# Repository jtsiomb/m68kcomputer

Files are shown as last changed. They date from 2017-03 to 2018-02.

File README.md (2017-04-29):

Homebrew 68k computer project 1
===============================



About
-----
The purpose of this project is to design a minimal but useful homebrew computer,
based on the Motorola 68010 16/32-bit processor.

The current hardware design is broken into a main processor board, and an I/O
and expansion board with an AVR microcontroller playing the role of UART, timer,
and RTC all in one.

Directory structure:

  * `hw` - hardware: kicad files and pdf schematics.
  * `fw_iolite` - firmware for the I/O controller.
  * `monitor` - ROM monitor program.

Project website: http://nuclear.mutantstargoat.com/hw/m68kcomp1

License
-------
Copyright (C) 2017 John Tsiombikas <nuclear@member.fsf.org>

You are free to use, reproduce, modify, redistribute any parts of this project,
provided you make any derivative work you release, freely available under the
same terms.

More specifically the hardware parts of this project are released under the
Creative Commons Attribution Share-Alike license (see `LICENSE.hw`
for details), and the software/firmware parts are released under the GNU General
Public License v3, or later (see `LICENSE.sw` for details).

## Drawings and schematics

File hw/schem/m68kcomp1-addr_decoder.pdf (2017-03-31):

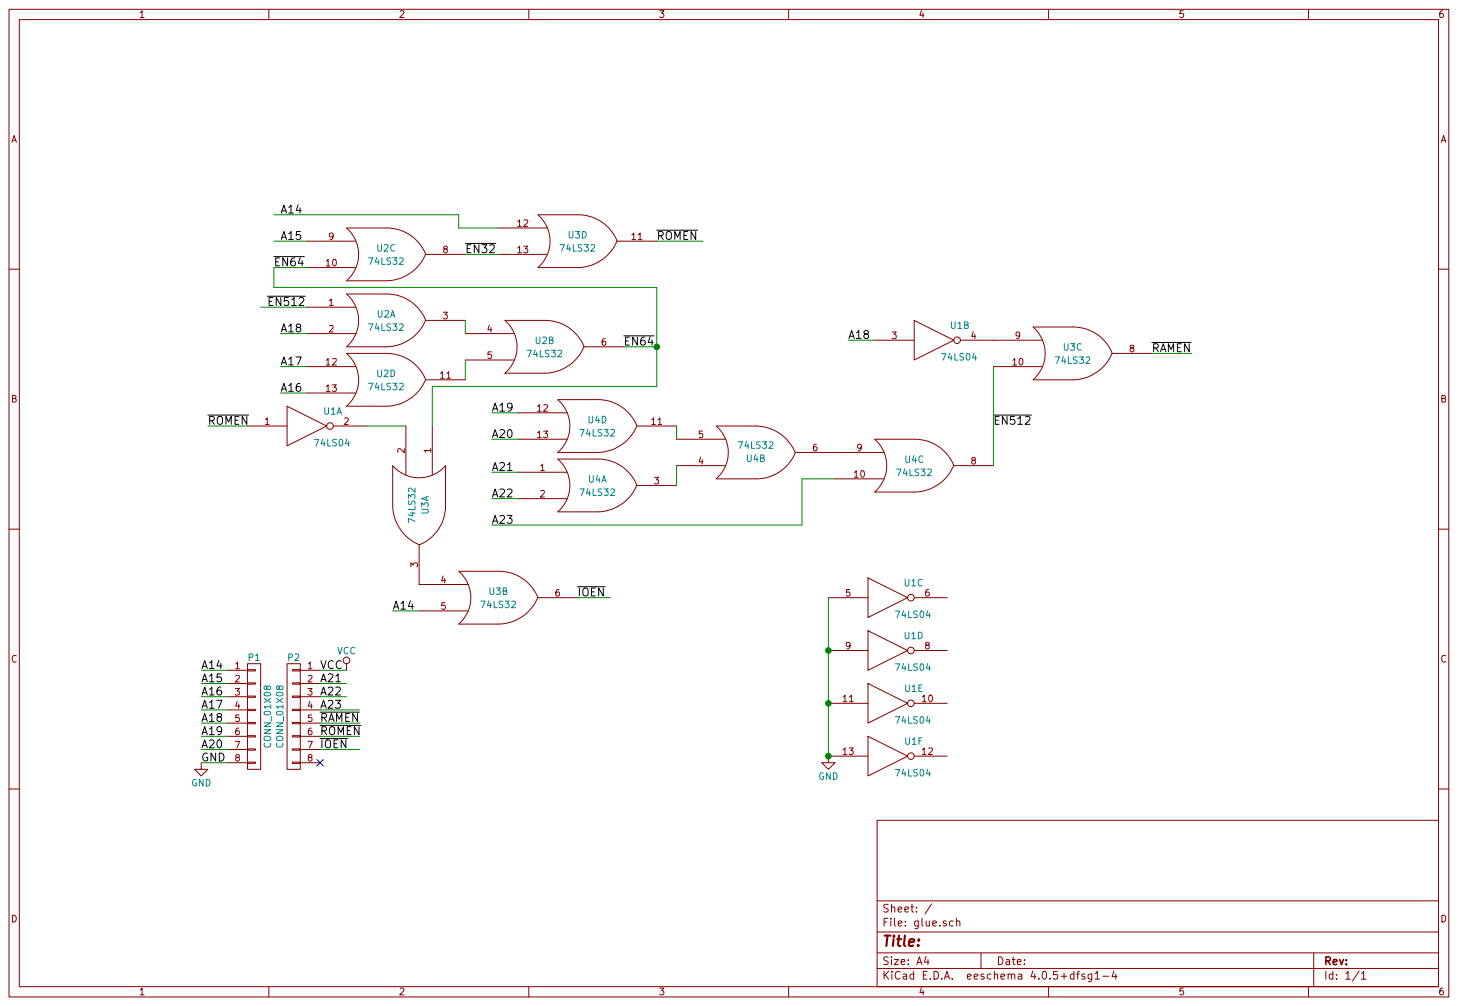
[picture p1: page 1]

File: glue.sch Sheet: /
Id: 1/1 Title:

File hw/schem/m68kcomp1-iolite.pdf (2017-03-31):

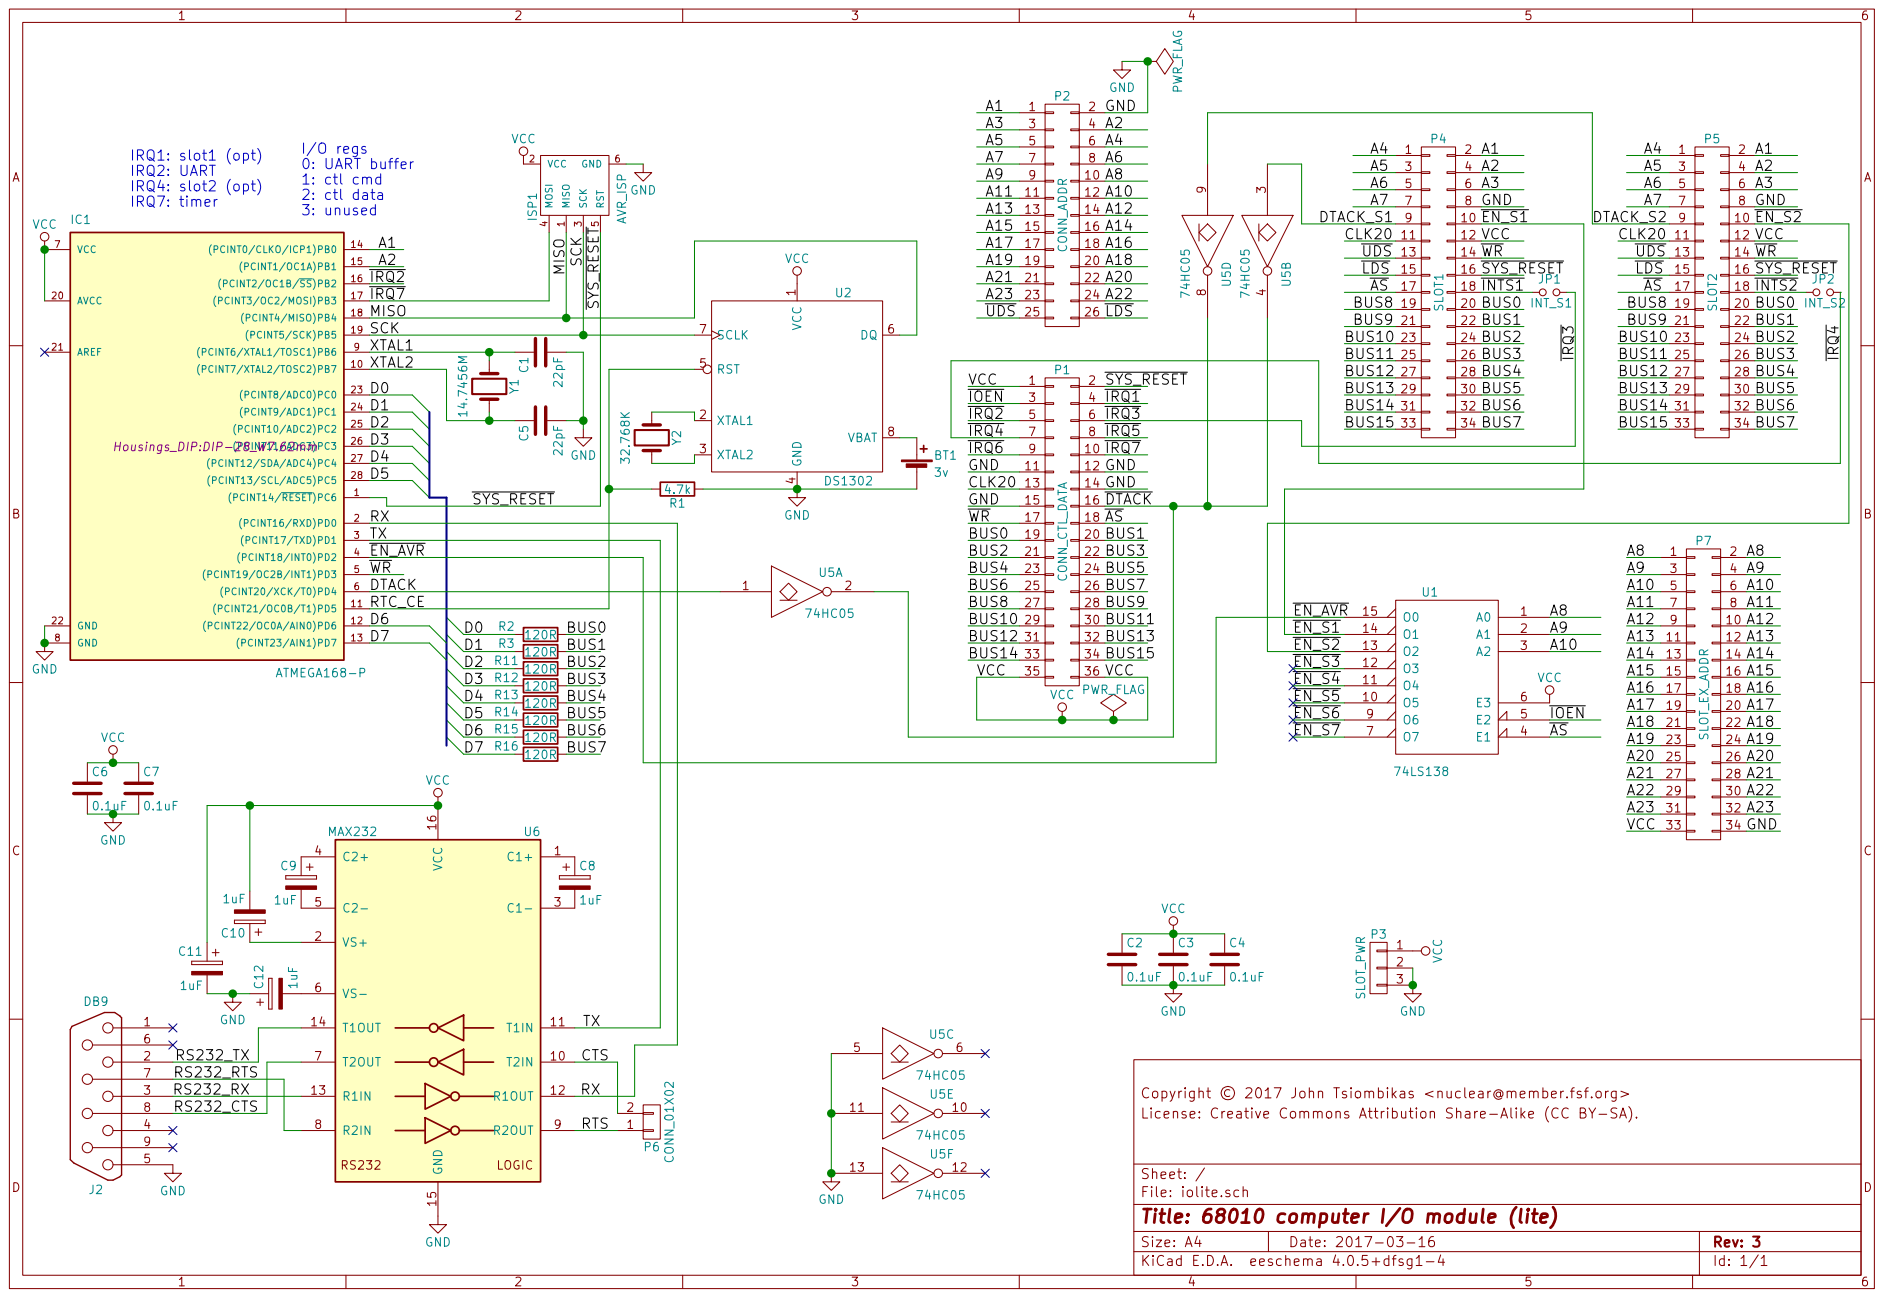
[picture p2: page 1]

I/O regs 0: UART buffer 1: ctl cmd

4 RST 5 DQ 6 SCLK 7 VBAT 8 U2 DS1302 DTACK Y2 32.768K

IOEN | 3 | | 4 | IRQ1
IRQ2 5 | | | 6 | IRQ3
IRQ4 7 | | 8 | IRQ5
IRQ6 9 | | 10 | IRQ7

3 RS232_RX

Copyright © 2017 John Tsiombikas <nuclear@member.fsf.org>
Id: 1/1 Title: 68010 computer I/O module (lite) File: iolite.sch Sheet: / License: Creative Commons Attribution Share-Alike (CC BY-SA).

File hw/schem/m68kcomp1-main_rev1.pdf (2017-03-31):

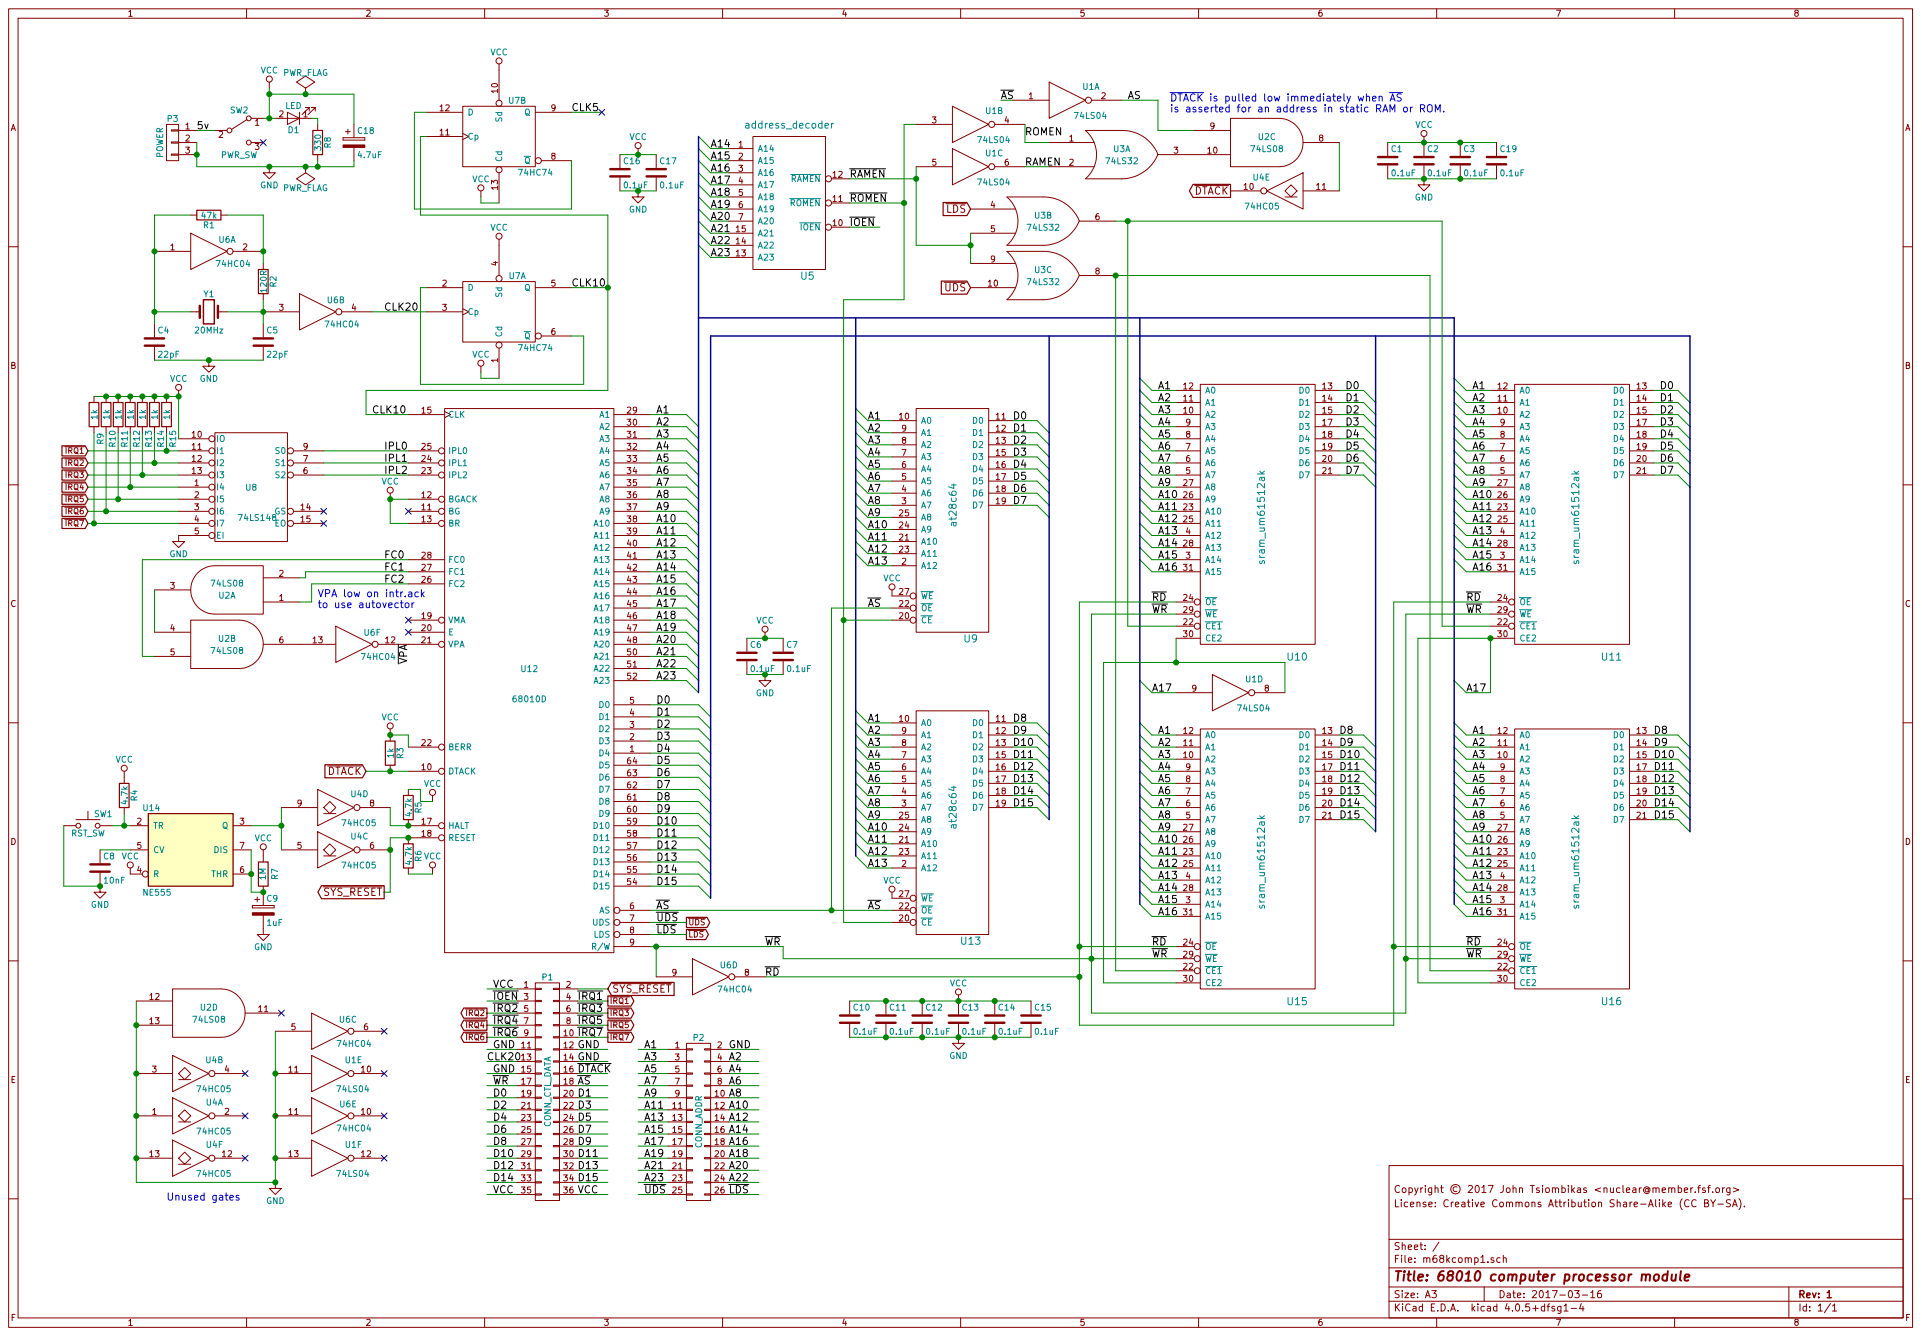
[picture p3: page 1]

DTACK is pulled low immediately when AS
is asserted for an address in static RAM or ROM.

IOEN | 3 | 4 | IRQ1
IRQ2 5 | | 6 | IRQ3
IRQ4 7 | | 8 | IRQ5

Copyright © 2017 John Tsiombikas <nuclear@member.fsf.org>
File: m68kcomp1.sch Sheet: / License: Creative Commons Attribution Share-Alike (CC BY-SA).

Id: 1/1 Title: 68010 computer processor module

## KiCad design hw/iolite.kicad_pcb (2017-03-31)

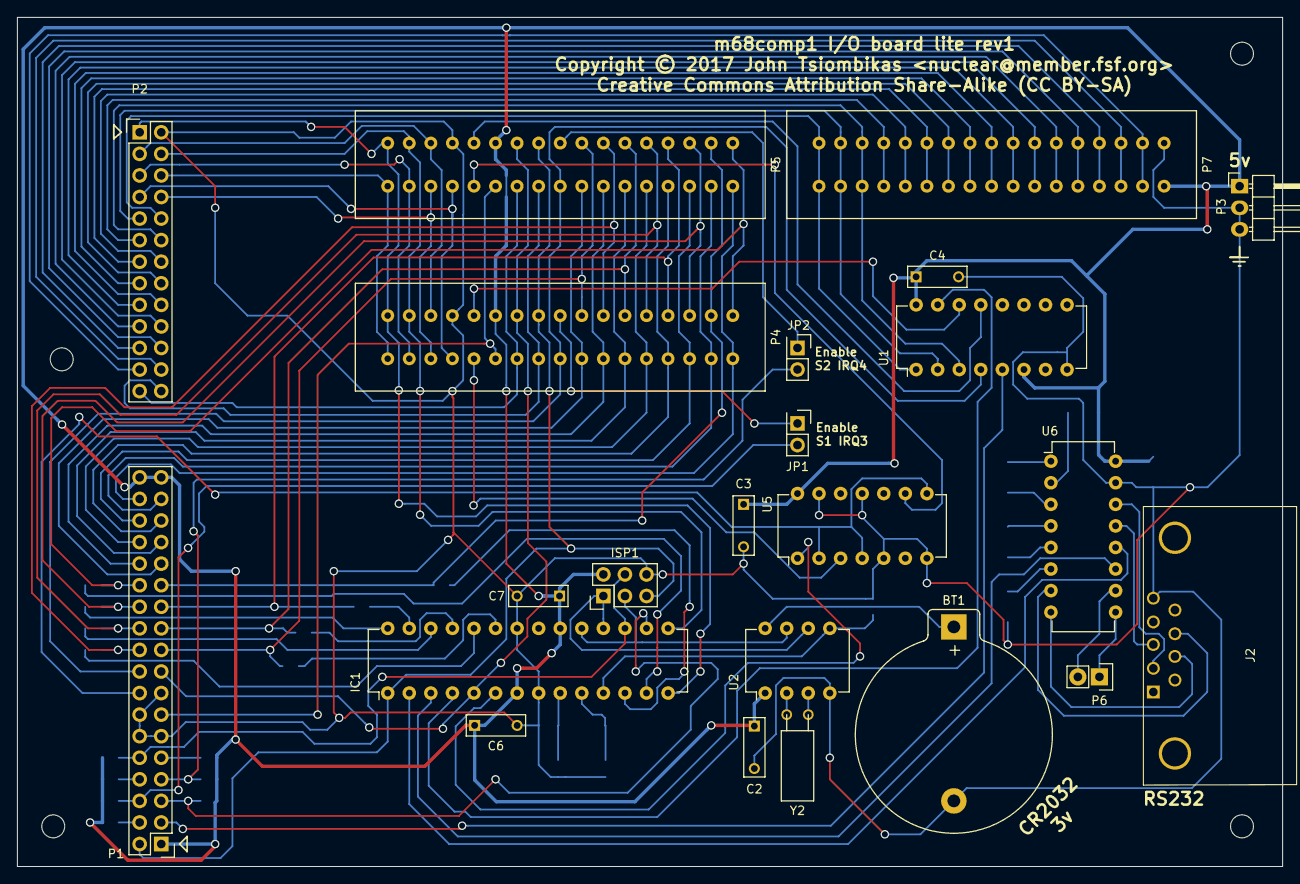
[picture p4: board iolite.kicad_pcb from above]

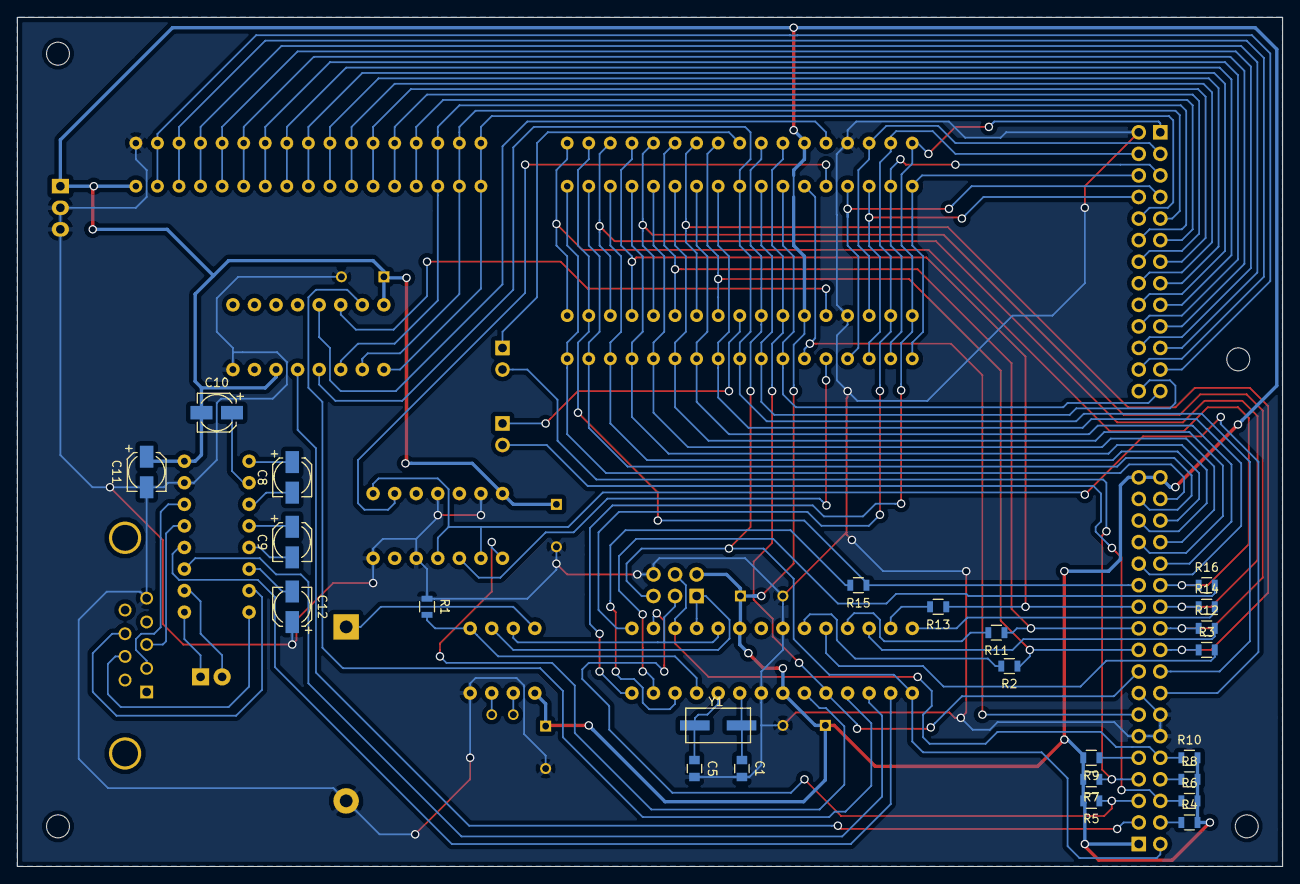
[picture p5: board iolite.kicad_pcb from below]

Board: 2 copper layers, 149.0 x 100.0 mm, 47 parts (24 on the bottom side), 94 nets.

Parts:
BT1: 3v; CR2032_CoinCell
C1, C5: 22pF; C_0805
C2, C3, C4, C6, C7: 0.1uF; C_Rect_L7_W2.5_P5
C8, C9, C10, C11, C12: 1uF; c_elec_4x5.7
IC1: ATMEGA168-P; DIP-28_W7.62mm
ISP1: AVR_ISP; Pin_Header_Straight_2x03
J2: DB9; DB9MC
JP1: INT_S1; Pin_Header_Straight_2x01
JP2: INT_S2; Pin_Header_Straight_2x01
P1: CONN_CTL_DATA; Pin_Header_Straight_2x18
P2: CONN_ADDR; Pin_Header_Straight_2x13
P3: SLOT_PWR; Pin_Header_Angled_1x03
P4: SLOT1; edgecon_2x17
P5: SLOT2; edgecon_2x17
P6: CONN_01X02; Pin_Header_Straight_1x02
P7: SLOT_EX_ADDR; edgecon_2x17
R1, R4, R5, R6, R7, R8, R9, R10: 4.7k; R_0805
R2, R3, R11, R12, R13, R14, R15, R16: 120R; R_0805
U1: 74LS138; DIP-16_W7.62mm
U2: DS1302; DIP-8_W7.62mm
U5: 74HC05; DIP-14_W7.62mm
U6: MAX232; DIP-16_W7.62mm
Y1: 14.7456M; crystal_smd_7.6x4.1
Y2: 32.768K; Crystal_Watch

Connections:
/A1: IC1.14, P2.1, P4.2, P5.2
/A2: IC1.15, P2.4, P4.4, P5.4
/A3: P2.3, P4.6, P5.6
/A4: P2.6, P4.1, P5.1
/A5: P2.5, P4.3, P5.3
/A6: P2.8, P4.5, P5.5
/A7: P2.7, P4.7, P5.7
/A8: P2.10, P7.1, P7.2, U1.1
/A9: P2.9, P7.3, P7.4, U1.2
/A10: P2.12, P7.5, P7.6, U1.3
/A11: P2.11, P7.7, P7.8
/A12: P2.14, P7.9, P7.10
/A13: P2.13, P7.11, P7.12
/A14: P2.16, P7.13, P7.14
/A15: P2.15, P7.15, P7.16
/A16: P2.18, P7.17, P7.18
/A17: P2.17, P7.19, P7.20
/A18: P2.20, P7.21, P7.22
/A19: P2.19, P7.23, P7.24
/A20: P2.22, P7.25, P7.26
/A21: P2.21, P7.27, P7.28
/A22: P2.24, P7.29, P7.30
/A23: P2.23, P7.31, P7.32
/BUS0: P1.19, P4.20, P5.20, R2.1
/BUS1: P1.20, P4.22, P5.22, R3.1
/BUS2: P1.21, P4.24, P5.24, R11.1
/BUS3: P1.22, P4.26, P5.26, R12.1
/BUS4: P1.23, P4.28, P5.28, R13.1
/BUS5: P1.24, P4.30, P5.30, R14.1
/BUS6: P1.25, P4.32, P5.32, R15.1
/BUS7: P1.26, P4.34, P5.34, R16.1
/BUS8: P1.27, P4.19, P5.19
/BUS9: P1.28, P4.21, P5.21
/BUS10: P1.29, P4.23, P5.23
/BUS11: P1.30, P4.25, P5.25
/BUS12: P1.31, P4.27, P5.27
/BUS13: P1.32, P4.29, P5.29
/BUS14: P1.33, P4.31, P5.31
/BUS15: P1.34, P4.33, P5.33
/CLK20: P1.13, P4.11, P5.11
/CTS: P6.2, U6.10
/D0: IC1.23, R2.2
/D1: IC1.24, R3.2
/D2: IC1.25, R11.2
/D3: IC1.26, R12.2
/D4: IC1.27, R13.2
/D5: IC1.28, R14.2
/D6: IC1.12, R15.2
/D7: IC1.13, R16.2
/DTACK: IC1.6, U5.1
/DTACK_S1: P4.9, U5.3
/DTACK_S2: P5.9, U5.9
/MISO: IC1.18, ISP1.1, U2.6
/RS232_CTS: J2.8, U6.7
/RS232_RTS: J2.7, U6.8
/RS232_RX: J2.3, U6.13
/RS232_TX: J2.2, U6.14
/RTC_CE: IC1.11, R1.2, U2.5
/RTS: P6.1, U6.9
/RX: IC1.2, U6.12
/SCK: IC1.19, ISP1.3, U2.7
/TX: IC1.3, U6.11
/XTAL1: C1.1, IC1.9, Y1.1
/XTAL2: C5.1, IC1.10, Y1.2
/~AS: P1.18, P4.17, P5.17, U1.4
/~DTACK: P1.16, U5.2, U5.4, U5.8
/~EN_AVR: IC1.4, U1.15
/~EN_S1: P4.10, U1.14
/~EN_S2: P5.10, U1.13
/~INTS1: JP1.1, P4.18
/~INTS2: JP2.1, P5.18
/~IOEN: P1.3, U1.5
/~IRQ1: P1.4, R4.1
/~IRQ2: IC1.16, P1.5, R5.1
/~IRQ3: JP1.2, P1.6, R6.1
/~IRQ4: JP2.2, P1.7, R7.1
/~IRQ5: P1.8, R8.1
/~IRQ6: P1.9, R9.1
/~IRQ7: IC1.17, ISP1.4, P1.10, R10.1
/~LDS: P2.26, P4.15, P5.15
/~SYS_RESET: IC1.1, ISP1.5, P1.2, P4.16, P5.16
/~UDS: P2.25, P4.13, P5.13
/~WR: IC1.5, P1.17, P4.14, P5.14
GND: BT1.2, C1.2, C2.2, C3.2, C4.2, C5.2, C6.2, C7.2, C11.2, C12.1, IC1.8, IC1.22, ISP1.6, J2.5, P1.11, P1.12, P1.14, P1.15, P2.2, P3.2, P3.3, P4.8, P5.8, P7.34, R1.1, U1.8, U2.4, U5.5, U5.7, U5.11, U5.13, U6.15
unnamed: BT1.1, U2.8
unnamed: C8.1, U6.1
unnamed: C8.2, U6.3
unnamed: C9.1, U6.4
unnamed: C9.2, U6.5
unnamed: C10.1, U6.2
unnamed: C12.2, U6.6
unnamed: U2.2, Y2.1
unnamed: U2.3, Y2.2
VCC: C2.1, C3.1, C4.1, C6.1, C7.1, C10.2, C11.1, IC1.7, IC1.20, ISP1.2, P1.1, P1.35, P1.36, P3.1, P4.12, P5.12, P7.33, R4.2, R5.2, R6.2, R7.2, R8.2, R9.2, R10.2, U1.6, U1.16, U2.1, U5.14, U6.16

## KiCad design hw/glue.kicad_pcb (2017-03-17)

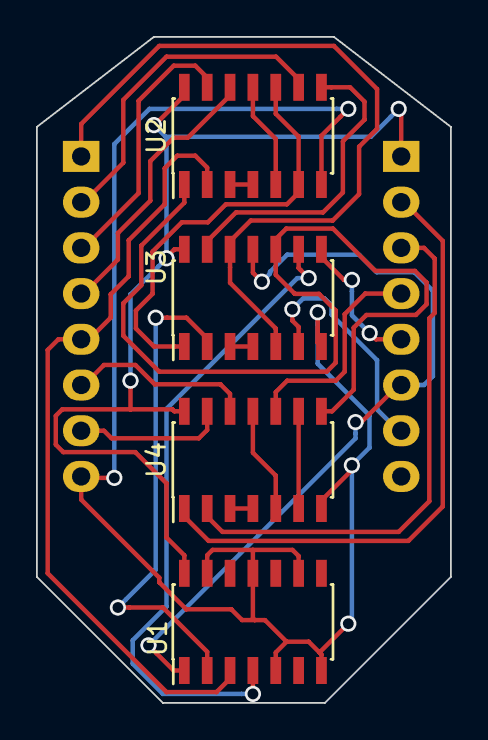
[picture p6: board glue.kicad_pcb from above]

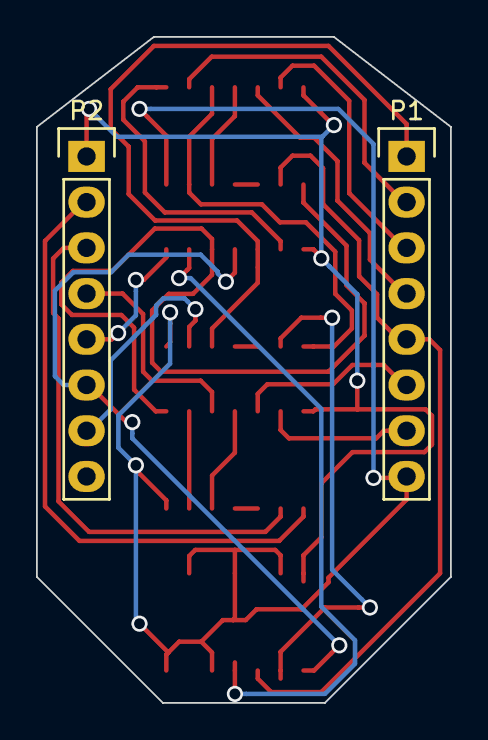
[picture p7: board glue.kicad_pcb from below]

Board: 2 copper layers, 23.0 x 37.0 mm, 6 parts (2 on the bottom side), 26 nets.

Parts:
P1, P2: CONN_01X08; Pin_Header_Straight_1x08
U1: 74LS04; SOIC-14_3.9x8.7mm_Pitch1.27mm
U2, U3, U4: 74LS32; SOIC-14_3.9x8.7mm_Pitch1.27mm

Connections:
/A14: P1.1, U3.5, U3.12
/A15: P1.2, U2.9
/A16: P1.3, U2.13
/A17: P1.4, U2.12
/A18: P1.5, U1.3, U2.2
/A19: P1.6, U4.12
/A20: P1.7, U4.13
/A21: P2.2, U4.1
/A22: P2.3, U4.2
/A23: P2.4, U4.10
/~EN32: U2.8, U3.13
/~EN64: U2.6, U2.10, U3.1
/~EN512: U2.1, U3.10, U4.8
/~IOEN: P2.7, U3.6
/~RAMEN: P2.5, U3.8
/~ROMEN: P2.6, U1.1, U3.11
GND: P1.8, U1.5, U1.7, U1.9, U1.11, U1.13, U2.7, U3.7, U4.7
unnamed: U1.2, U3.2
unnamed: U1.4, U3.9
unnamed: U2.3, U2.4
unnamed: U2.5, U2.11
unnamed: U3.3, U3.4
unnamed: U4.3, U4.4
unnamed: U4.6, U4.9
unnamed: U4.5, U4.11
VCC: P2.1, U1.14, U2.14, U3.14, U4.14

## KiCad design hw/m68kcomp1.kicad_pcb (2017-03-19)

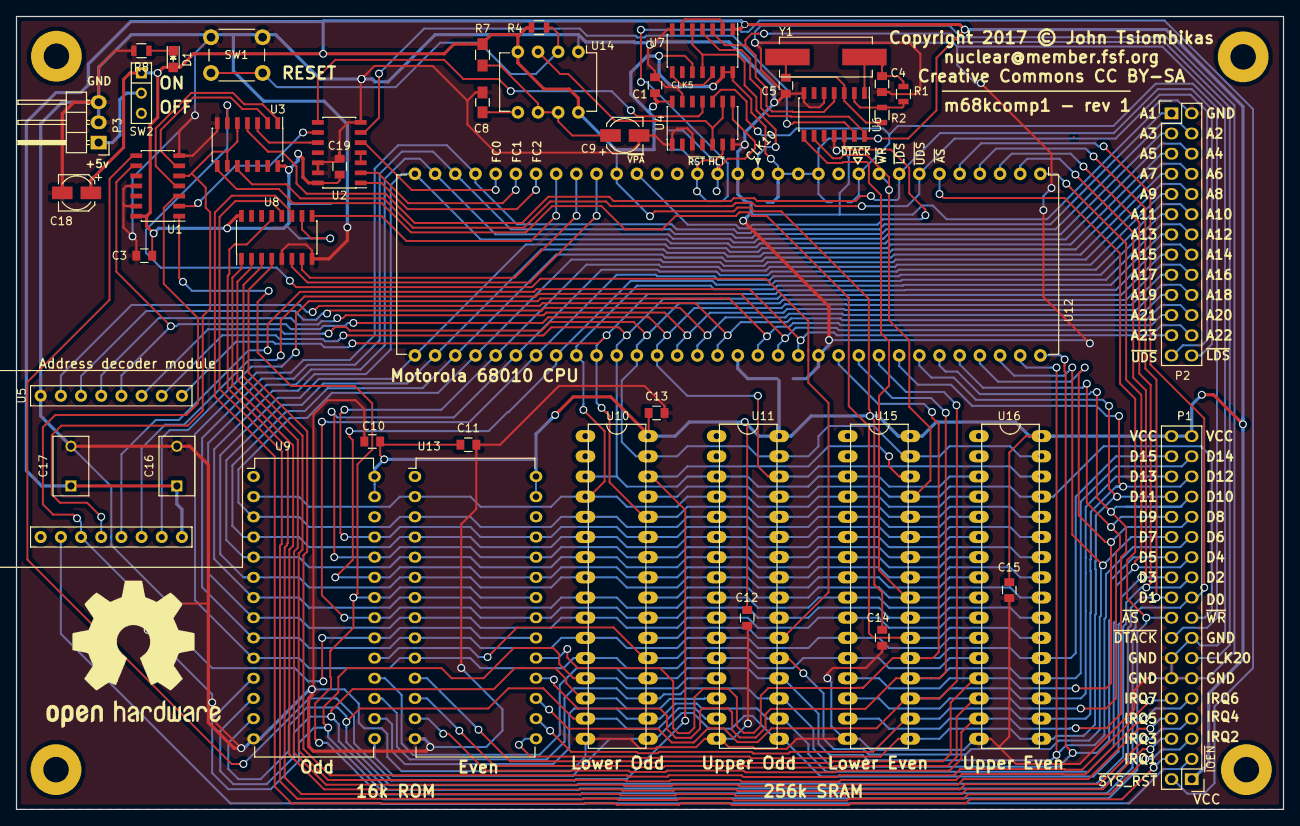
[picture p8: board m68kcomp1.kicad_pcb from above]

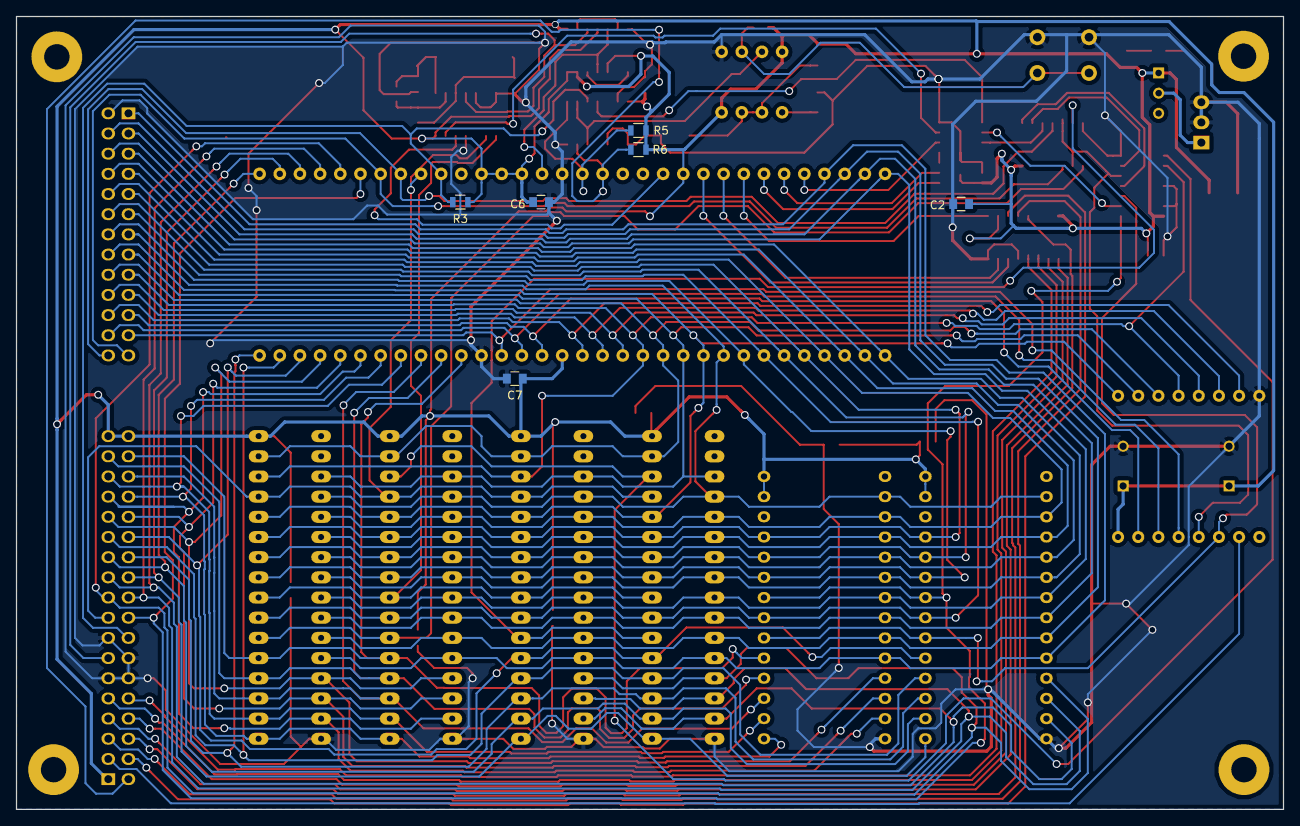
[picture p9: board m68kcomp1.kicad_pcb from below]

Board: 2 copper layers, 159.5 x 99.8 mm, 50 parts (6 on the bottom side), 89 nets.

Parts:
C1, C2, C3, C6, C7, C10, C11, C12, C13, C14, C15, C19: 0.1uF; C_0805
C4, C5: 22pF; C_0805
C8: 10nF; C_0805_HandSoldering
C9: 1uF; c_elec_4x5.7
C16, C17: 0.1uF; C_Disc_D7.5_P5
C18: 4.7uF; c_elec_4x5.7
D1: LED; LED_0805
P1: CONN_CTL_DATA; Pin_Header_Straight_2x18
P2: CONN_ADDR; Pin_Header_Straight_2x13_oval
P3: POWER; Pin_Header_Angled_1x03
R1: 47k; R_0805
R2: 120R; R_0805
R3, R4, R5, R6: 4.7k; R_0805
R7: 1M; R_0805_HandSoldering
R8: 330; R_0805
SW1: RST_SW; SW_PUSH_6mm
SW2: PWR_SW; SW_Micro_SPST
U1: 74LS04; SOIC-14_3.9x8.7mm_Pitch1.27mm
U2: 74LS08; SOIC-14_3.9x8.7mm_Pitch1.27mm
U3: 74LS32; SOIC-14_3.9x8.7mm_Pitch1.27mm
U4: 74HC05; SOIC-14_3.9x8.7mm_Pitch1.27mm
U5: address_decoder; addr_dec_module
U6: 74HC04; SOIC-14_3.9x8.7mm_Pitch1.27mm
U7: 74HC74; SOIC-14_3.9x8.7mm_Pitch1.27mm
U8: 74LS148; SOIC-16_3.9x9.9mm_Pitch1.27mm
U9, U13: at28c64; DIP-28_W15.24mm_oval
U10, U11, U15, U16: sram_um61512ak; DIP-32L
U12: 68010D; DIP-64_W22.86mm
U14: NE555; DIP-8_W7.62mm
Y1: 20MHz; Crystal_HC49-SD_SMD

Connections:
/5v: P3.1, SW2.2
/A1: P2.1, U9.10, U10.12, U11.12, U12.29, U13.10, U15.12, U16.12
/A2: P2.4, U9.9, U10.11, U11.11, U12.30, U13.9, U15.11, U16.11
/A3: P2.3, U9.8, U10.10, U11.10, U12.31, U13.8, U15.10, U16.10
/A4: P2.6, U9.7, U10.9, U11.9, U12.32, U13.7, U15.9, U16.9
/A5: P2.5, U9.6, U10.8, U11.8, U12.33, U13.6, U15.8, U16.8
/A6: P2.8, U9.5, U10.7, U11.7, U12.34, U13.5, U15.7, U16.7
/A7: P2.7, U9.4, U10.6, U11.6, U12.35, U13.4, U15.6, U16.6
/A8: P2.10, U9.3, U10.5, U11.5, U12.36, U13.3, U15.5, U16.5
/A9: P2.9, U9.25, U10.27, U11.27, U12.37, U13.25, U15.27, U16.27
/A10: P2.12, U9.24, U10.26, U11.26, U12.38, U13.24, U15.26, U16.26
/A11: P2.11, U9.21, U10.23, U11.23, U12.39, U13.21, U15.23, U16.23
/A12: P2.14, U9.23, U10.25, U11.25, U12.40, U13.23, U15.25, U16.25
/A13: P2.13, U9.2, U10.4, U11.4, U12.41, U13.2, U15.4, U16.4
/A14: P2.16, U5.1, U10.28, U11.28, U12.42, U15.28, U16.28
/A15: P2.15, U5.2, U10.3, U11.3, U12.43, U15.3, U16.3
/A16: P2.18, U5.3, U10.31, U11.31, U12.44, U15.31, U16.31
/A17: P2.17, U1.9, U5.4, U11.30, U12.45, U16.30
/A18: P2.20, U5.5, U12.46
/A19: P2.19, U5.6, U12.47
/A20: P2.22, U5.7, U12.48
/A21: P2.21, U5.15, U12.50
/A22: P2.24, U5.14, U12.51
/A23: P2.23, U5.13, U12.52
/AS: U1.2, U2.9
/CLK10: U7.5, U7.11, U12.15
/CLK20: P1.13, U6.4, U7.3
/D0: P1.19, U9.11, U10.13, U11.13, U12.5
/D1: P1.20, U9.12, U10.14, U11.14, U12.4
/D2: P1.21, U9.13, U10.15, U11.15, U12.3
/D3: P1.22, U9.15, U10.17, U11.17, U12.2
/D4: P1.23, U9.16, U10.18, U11.18, U12.1
/D5: P1.24, U9.17, U10.19, U11.19, U12.64
/D6: P1.25, U9.18, U10.20, U11.20, U12.63
/D7: P1.26, U9.19, U10.21, U11.21, U12.62
/D8: P1.27, U12.61, U13.11, U15.13, U16.13
/D9: P1.28, U12.60, U13.12, U15.14, U16.14
/D10: P1.29, U12.59, U13.13, U15.15, U16.15
/D11: P1.30, U12.58, U13.15, U15.17, U16.17
/D12: P1.31, U12.57, U13.16, U15.18, U16.18
/D13: P1.32, U12.56, U13.17, U15.19, U16.19
/D14: P1.33, U12.55, U13.18, U15.20, U16.20
/D15: P1.34, U12.54, U13.19, U15.21, U16.21
/FC0: U2.5, U12.28
/FC1: U2.2, U12.27
/FC2: U2.1, U12.26
/IPL0: U8.9, U12.25
/IPL1: U8.7, U12.24
/IPL2: U8.6, U12.23
/RAMEN: U1.6, U3.2
/ROMEN: U1.4, U3.1
/~AS: P1.18, U1.1, U9.22, U12.6, U13.22
/~IOEN: P1.3, U5.10
/~RAMEN: U1.5, U3.5, U3.9, U5.12
/~RD: U6.8, U10.24, U11.24, U15.24, U16.24
/~ROMEN: U1.3, U5.11, U9.20, U13.20
/~VPA: U6.12, U12.21
/~WR: P1.17, U6.9, U10.29, U11.29, U12.9, U15.29, U16.29
GND: C1.2, C2.2, C3.2, C4.2, C5.2, C6.2, C7.2, C8.2, C9.2, C10.2, C11.2, C12.2, C13.2, C14.2, C15.2, C16.2, C17.2, C18.2, C19.2, P1.11, P1.12, P1.14, P1.15, P2.2, P3.2, P3.3, R8.2, SW1.1, U1.7, U1.11, U1.13, U2.7, U2.12, U2.13, U3.7, U4.1, U4.3, U4.7, U4.13, U5.8, U6.5, U6.7, U6.11, U7.7, U8.5, U8.8, U9.14, U10.16, U11.16, U12.16, U12.53, U13.14, U14.1, U15.16, U16.16
unnamed: C4.1, R1.2, U6.1, Y1.1
unnamed: C5.1, R2.2, U6.3, Y1.2
unnamed: C8.1, U14.5
unnamed: C9.1, R7.1, U14.6, U14.7
unnamed: D1.1, R8.1
unnamed: R1.1, R2.1, U6.2
unnamed: R4.2, SW1.2, U14.2
unnamed: R5.2, U4.8, U12.17
unnamed: U1.8, U10.30, U15.30
unnamed: U2.3, U2.4
unnamed: U2.6, U6.13
unnamed: U2.8, U4.11
unnamed: U2.10, U3.3
unnamed: U7.2, U7.6
unnamed: U7.8, U7.12
unnamed: U3.6, U10.22, U11.22
unnamed: U4.5, U4.9, U14.3
unnamed: U3.8, U15.22, U16.22
VCC: C1.1, C2.1, C3.1, C6.1, C7.1, C10.1, C11.1, C12.1, C13.1, C14.1, C15.1, C16.1, C17.1, C18.1, C19.1, D1.2, P1.1, P1.35, P1.36, R3.1, R4.1, R5.1, R6.2, R7.2, SW2.1, U1.14, U2.14, U3.14, U4.14, U5.16, U6.14, U7.1, U7.4, U7.10, U7.13, U7.14, U8.10, U8.16, U9.27, U9.28, U10.32, U11.32, U12.12, U12.13, U12.14, U12.22, U12.49, U13.27, U13.28, U14.4, U14.8, U15.32, U16.32
~DTACK: P1.16, R3.2, U4.10, U12.10
~IRQ1: P1.4, U8.11
~IRQ2: P1.5, U8.12
~IRQ3: P1.6, U8.13
~IRQ4: P1.7, U8.1
~IRQ5: P1.8, U8.2
~IRQ6: P1.9, U8.3
~IRQ7: P1.10, U8.4
~LDS: P2.26, U3.4, U12.8
~SYS_RESET: P1.2, R6.1, U4.6, U12.18
~UDS: P2.25, U3.10, U12.7

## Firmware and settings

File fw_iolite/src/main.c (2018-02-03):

#include "config.h"

#include <stdio.h>
#include <stdlib.h>
#include <string.h>
#include <ctype.h>
#include <stdint.h>
#include <avr/io.h>
#include <avr/interrupt.h>
#include <util/delay.h>
#include "serial.h"
#include "ds1302rtc.h"

void init(void);
void do_read(unsigned char addr);
void do_write(unsigned char addr);
void pulse_dtack(void);
unsigned char rdata(void);
void wdata(unsigned char data);
const char *day_of_week(int x);

unsigned char last_cmd;
unsigned char rtc_seq_idx = 0;

struct rtc_time tm;
struct rtc_date date;


int main(void)
{
	init();

	rtc_get_time(&tm);
	rtc_get_date(&date);

	/*
	printf("\r\nI/O board lite debug\r\n");
	printf("%s %02d/%02d/%d - %02d:%02d.%02ds\r\n", day_of_week(date.dow), date.day,
			date.month, date.year, tm.hour, tm.min, tm.sec);
	*/

	for(;;) {
		if((PIND & PD_ENABLE_BIT) == 0) {
			int addr = PINB & 3;
			if(PIND & PD_RDWR_BIT) {
				do_read(addr);
			} else {
				do_write(addr);
			}
		}
	}
	return 0;
}

void init(void)
{
	/* IRQ bits outputs, the rest inputs */
	DDRB = PB_IRQ_UART_BIT | PB_IRQ_TIMER_BIT | PB_RTC_CLK_BIT;
	PORTB = PB_IRQ_UART_BIT | PB_IRQ_TIMER_BIT; /* IRQ outputs high, inputs without pullups */
	DDRD = PD_DTACK_BIT | PD_RTC_CE_BIT; /* DTACK and RTC_CE are outputs, the rest are inputs */
	PORTD = 0;	/* all outputs low, the rest inputs without pullups */
	/* port C is the data bus: default to inputs without pullups */
	DDRC = 0;
	PORTC = 0;

	/* initialize the UART and enable interrupts */
	init_serial(115200);
	sei();

	rtc_init();
}

void do_read(unsigned char addr)
{
	unsigned char data;

	switch(addr) {
	case REG_UART_BUFFER:
		data = getchar();
		/*printf("DBG: %d", data);
		if(isprint(data)) {
			printf(" (%c)", data);
		}
		printf("\r\n");*/
		/* also acknowledge the interrupt if it's pending and
		 * there are no more bytes to read
		 */
		cli();
		if(!have_input()) {
			PORTB |= PB_IRQ_UART_BIT;
		}
		sei();
		break;

	case REG_CTL_DATA:
		data = rdata();
		break;

	default:
		data = 0xff;
	}

	/* drive data bus */
	DDRC = PC_DATA_MASK;
	DDRD |= PD_DATA_MASK;

	/* write the data to the data bus */
	PORTC = data;
	PORTD = (PORTD & ~PD_DATA_MASK) | (data & PD_DATA_MASK);

	pulse_dtack();
	while((PIND & PD_ENABLE_BIT) == 0);

	/* read done, tri-state data bus */
	DDRC = 0;
	DDRD &= ~PD_DATA_MASK;
}

void do_write(unsigned char addr)
{
	/* read the value off the data bus */
	unsigned char data = (PINC & PC_DATA_MASK) | (PIND & PD_DATA_MASK);

	switch(addr) {
	case REG_UART_BUFFER:
		putchar(data);
		fflush(stdout);
		/*printf("DBG: write(%x)->'%c' (%x)\n", (unsigned int)addr, data, (unsigned int)data);*/
		break;

	case REG_CTL_CMD:
		last_cmd = data;
		switch(data) {
		case CMD_TIME:
			rtc_get_time(&tm);
			rtc_seq_idx = 0;
			break;
		case CMD_DATE:
			rtc_get_date(&date);
			rtc_seq_idx = 0;
			break;
		default:
			break;
		}
		break;

	case REG_CTL_DATA:
		wdata(data);
		break;

	case REG_INT_ACK:	/* interrupt acknowledge */
		switch(data) {
		case 2:
			PORTB |= PB_IRQ_UART_BIT;
			break;
		case 7:
			PORTB |= PB_IRQ_TIMER_BIT;
			break;
		default:
			break;
		}
		break;
	}

	pulse_dtack();
	while((PIND & PD_ENABLE_BIT) == 0);
}

void pulse_dtack(void)
{
	PORTD |= PD_DTACK_BIT;
	asm volatile ("nop\n\t");
	PORTD &= ~PD_DTACK_BIT;
}

/* processor is reading from the data register */
unsigned char rdata(void)
{
	switch(last_cmd) {
	case CMD_TIME:
		return ((int*)&tm)[rtc_seq_idx++];

	case CMD_DATE:
		if(rtc_seq_idx == 0) {
			++rtc_seq_idx;
			return date.year - 2000;
		} else {
			return ((int*)&date)[rtc_seq_idx++];
		}

	case CMD_INVALID:
	default:
		break;
	}
	return 0xff;
}

/* processor is writing to the data register */
void wdata(unsigned char data)
{
	switch(last_cmd) {
	case CMD_TIME:
		((int*)&tm)[rtc_seq_idx] = data;
		if(++rtc_seq_idx >= 3) {
			rtc_set_time(tm.hour, tm.min, tm.sec);
			last_cmd = CMD_INVALID;
		}
		break;

	case CMD_DATE:
		((int*)&date)[rtc_seq_idx] = data;
		if(++rtc_seq_idx == 3) {
			date.year = 2000 + date.year;
			rtc_set_date(date.year, date.month, date.day);
		} else if(rtc_seq_idx >= 4) {
			rtc_set_weekday(date.dow);
			last_cmd = CMD_INVALID;
		}
		break;

	case CMD_INVALID:
	default:
		break;
	}
}

/* this is called by the UART interrupt to signal that we got some data
 * and we should interrupt the processor
 */
void recv_data_intr(void)
{
	/* raise a 68k interrupt */
	PORTB &= ~PB_IRQ_UART_BIT;
}

const char *day_of_week(int x)
{
	static const char *daystr[] = { "Monday", "Tuesday", "Wednesday",
		"Thursday", "Friday", "Saturday", "Sunday" };
	return daystr[x - 1];
}

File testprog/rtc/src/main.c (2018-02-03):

#include <stdio.h>
#include <stdlib.h>
#include <string.h>
#include <ctype.h>
#include "intr.h"
#include "tctl.h"
#include "rtc.h"

void proc_input(char c);
int tokenize_input(void);
void runcmd(void);
const char *day_of_week(int x);

static char input[128];
static short cur;

static char *argv[64];
static short argc;

int main(void)
{
	int c;

	printf("RTC test program\n");
	init_intr();

	while((c = getchar()) != 4) {
		proc_input(c);
	}

	cleanup_intr();
	return 0;
}

void proc_input(char c)
{
	int i;

	switch(c) {
	case '\b':
	case 127:
		if(cur > 0) {
			--cur;
			if(c != '\b') {
				putchar('\b');
			}
			printf(" \b");
		}
		break;

	case 21:	/* ctrl-U */
		if(cur > 0) {
			printf(TCTL_KILL_HOME);
			cur = 0;
		}
		break;

	case '\n':
		input[cur] = 0;
		cur = 0;

		if(tokenize_input()) {
			runcmd();
		}
		break;

	default:
		if(cur < sizeof input - 1) {
			input[cur++] = c;
		}
	}
}

static char *skip_space(char *s)
{
	while(*s && isspace(*s)) ++s;
	return s;
}

int tokenize_input(void)
{
	char *ptr = skip_space(input);
	if(!*ptr) {
		argc = 0;
		argv[0] = 0;
		return 0;
	}

	argc = 1;
	argv[0] = ptr;

	while(*ptr) {
		if(isspace(*ptr)) {
			*ptr = 0;
			ptr = skip_space(ptr + 1);
			if(*ptr) {
				argv[argc++] = ptr;
			}
		} else {
			++ptr;
		}
	}

	argv[argc] = 0;
	return argc;
}

void runcmd(void)
{
	struct rtc_time tm;
	struct rtc_date date;
	char *endp;

	if(!argc) return;

	if(strcasecmp(argv[0], "time") == 0) {
		if(!argv[1]) {
			rtc_get_time(&tm);
			printf("current time: %02d:%02d.%02ds\n", tm.hour, tm.min, tm.sec);
		} else {
			if(argc < 3) {
				goto time_usage;
			} else if(argc < 4) {
				tm.sec = 0;
			} else {
				tm.sec = strtol(argv[3], &endp, 10);
				if(*endp) goto time_usage;
			}

			tm.hour = strtol(argv[1], &endp, 10);
			if(*endp) goto time_usage;
			tm.min = strtol(argv[2], &endp, 10);
			if(*endp) goto time_usage;

			rtc_set_time(tm.hour, tm.min, tm.sec);
		}

	} else if(strcasecmp(argv[0], "date") == 0) {
		if(!argv[1]) {
			rtc_get_date(&date);
			printf("current date: %s %02d/%02d/%d\n", day_of_week(date.dow),
					date.day, date.month, date.year);
		} else {
			if(argc < 4) {
				goto date_usage;
			} else if(argc < 5) {
				date.dow = 0;
			} else {
				date.dow = strtol(argv[4], &endp, 10);
				if(*endp) goto date_usage;
			}

			date.year = strtol(argv[1], &endp, 10);
			if(*endp) goto date_usage;
			date.month = strtol(argv[2], &endp, 10);
			if(*endp) goto date_usage;
			date.day = strtol(argv[3], &endp, 10);
			if(*endp) goto date_usage;

			rtc_set_date(date.year, date.month, date.day, date.dow);
		}
	}

	return;

time_usage:
	printf("usage: time <hour> <min> [sec]\n");
	return;

date_usage:
	printf("usage: date <year> <month> <day> [day of week (0 = monday)]\n");
}

const char *day_of_week(int x)
{
	static const char *daystr[] = { "Monday", "Tuesday", "Wednesday",
		"Thursday", "Friday", "Saturday", "Sunday" };
	return daystr[x - 1];
}

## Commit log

2017-03-04 DRAM changes
    [dram_ctl.sch]
2017-03-07 dram controller *might* work
    [dram_ctl.sch, m68kcomp1.sch]
2017-03-07 forgot to add the dram controller circuit
2017-03-14 static low ram
    [m68kcomp1.sch]
2017-03-17 moving along
    [dram_ctl.sch, glue.kicad_pcb, glue.sch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]
2017-03-17 laying out the board
    [m68kcomp1.kicad_pcb]
2017-03-18 holy shit laying out this PCB takes a lot of time
    [m68kcomp1.kicad_pcb, m68kcomp1.sch]
2017-03-18 pcb layout almost done
    [m68kcomp1.kicad_pcb, m68kcomp1.sch]
2017-03-19 completed pcb layout
    [m68kcomp1.kicad_pcb]
2017-03-19 changes for manufacture
    [m68kcomp1.kicad_pcb, m68kcomp1.sch]
2017-03-19 added schematic pdf
2017-03-20 started on the I/O board
    [io.sch]
2017-03-20 I/O board schematic done
    [io.sch]
2017-03-21 io board pcb layout in progress
    [io.kicad_pcb, io.sch]
2017-03-23 new layout
    [io.kicad_pcb, io.sch, m68kcomp1.sch]
2017-03-23 added gerbers dir to .hgignore
2017-03-23 layout progresses
    [io.kicad_pcb]
2017-03-24 I/O PCB almost done
    [io.kicad_pcb]
2017-03-24 mostly done
    [io.kicad_pcb, io.sch]
2017-03-24 increased the via pad size
    [io.kicad_pcb]
2017-03-28 io lite
    [io.kicad_pcb, io.sch, iolite.kicad_pcb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]
2017-03-31 updated schematics
    [iolite.kicad_pcb, iolite.sch, m68kcomp1.sch]
2017-04-01 changed directory structured, moved everything into hw/ to prepare for merging the software part in the same repo
    [dram_ctl.sch, glue.kicad_pcb, glue.sch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]
2017-04-02 interrupts working, UART transmit/receive (receive works only with word sizes)
2017-04-03 found the byte-transfer bug. Need to use odd I/O addresses the way I wired up the AVR in the I/O board
2017-04-03 changed the data bus hookup to the AVR microcontroller, to use the upper data lines instead of the lower ones.
    [iolite.sch]
2017-04-06 ops, changed the UART buffer size for debugging and forgot to also change the wrap-around mask
2017-04-06 as a matter of fact, let's make the mask (SZ - 1) to avoid similar problems in the future
    [serial.c]
2017-04-07 debugging intermittent I/O DTACK issue
    [main.c, serial.c]
2017-04-07 updated schematic
    [m68kcomp1.sch]
2017-04-07 converting \n -> \r\n in printstr
2017-04-09 changed default UART speed to 115200
2017-04-09 - fixed program names in test program makefiles - made the koch curve draw visibly (but more slowly)
    [main.c]
2018-02-03 updated the firmware to correctly handle RTC read/write requests from the processor
    [main.c]

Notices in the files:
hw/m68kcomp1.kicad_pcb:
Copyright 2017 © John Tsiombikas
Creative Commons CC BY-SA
